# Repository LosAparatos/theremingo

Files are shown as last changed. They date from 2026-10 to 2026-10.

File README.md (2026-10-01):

# Theremingo
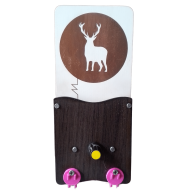
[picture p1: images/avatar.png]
Theremingo


A handmade analog electromagnetic theremin, designed and built by [Los Aparatos](https://losaparatos.com.ar) in Tucumán, Argentina.

## What is it?

Theremingo is an analog theremin — a touchless electronic instrument played by moving your hands near its antennas, which affect pitch and volume through electromagnetic field disturbance. No microcontroller, no code: fully analog circuitry.

## Repository contents

- `/schematics` — circuit design files, created in **EagleCAD (v9.0)**. You'll need Eagle (or a compatible tool like KiCad with an Eagle import plugin) to open the native files.
- `/images` — photos of the finished instrument, including its final enclosure — a deer-shaped antenna cut as an SVG, not included among the schematic files.

## About Los Aparatos

Los Aparatos is an electronic design studio building experimental musical instruments — synthesizers, sound toys and DIY kits — handmade in Tucumán, Argentina, since 2007.

Other instruments: [Auduina](https://gitlab.com/los-aparatos/auduina) (granular synth), Drawdio (a sound pencil that turns drawing into sound), CoyuyoC (a drone synth).

## Where to buy

[losaparatos.com.ar](https://losaparatos.com.ar) · [Tindie](https://www.tindie.com/stores/mateoaparato/) · [Etsy](https://losaparatos.etsy.com) · [Reverb](https://reverb.com/shop/los-aparatos)

## License

[CC BY-NC-SA 4.0](https://creativecommons.org/licenses/by-nc-sa/4.0/)

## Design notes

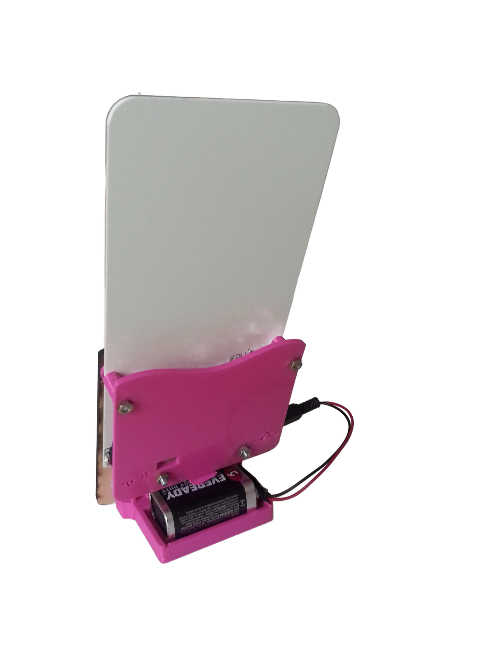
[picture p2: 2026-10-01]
images/2024-01-17T23_02_19.963Z-3806eb7695ffbf5aecbad718a80b5527.png

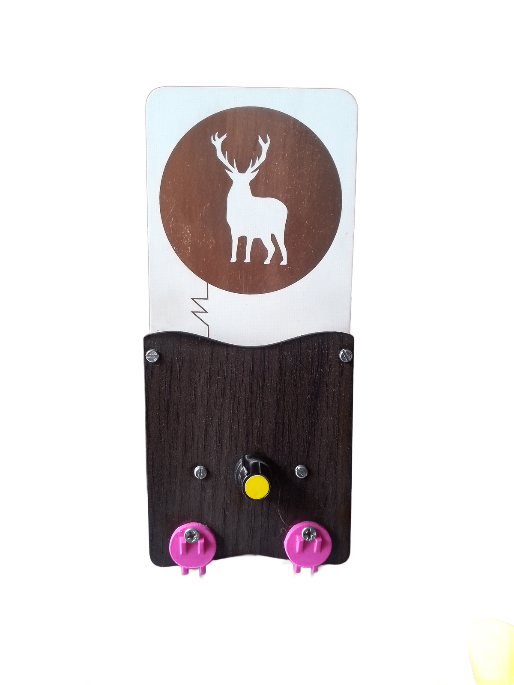
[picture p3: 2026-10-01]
images/2024-01-17T23_02_19.963Z-660f86e07b97e593479c22d0fbce8938.png

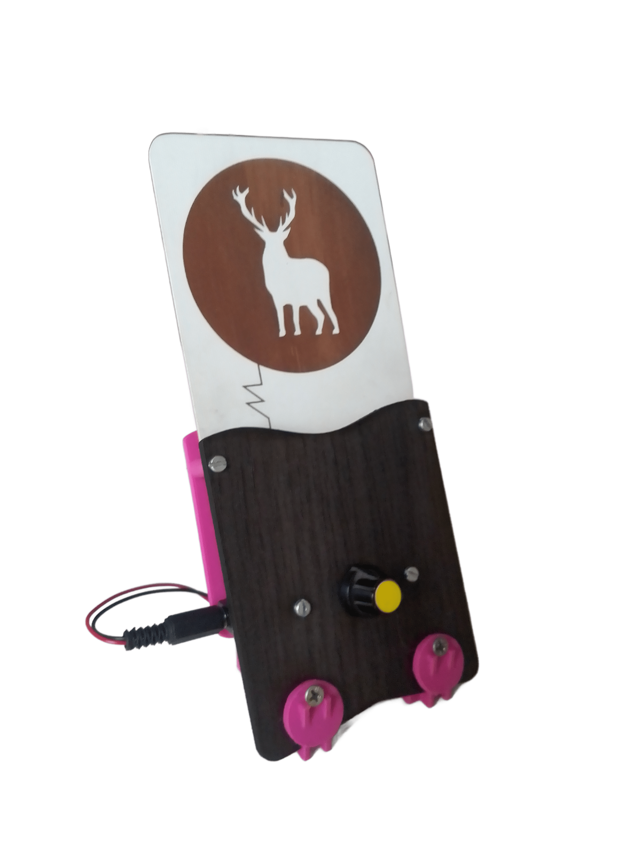
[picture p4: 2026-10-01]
images/2024-01-17T23_02_19.963Z-f0b44ce99c8f05dc5610db6ddd29624c.png

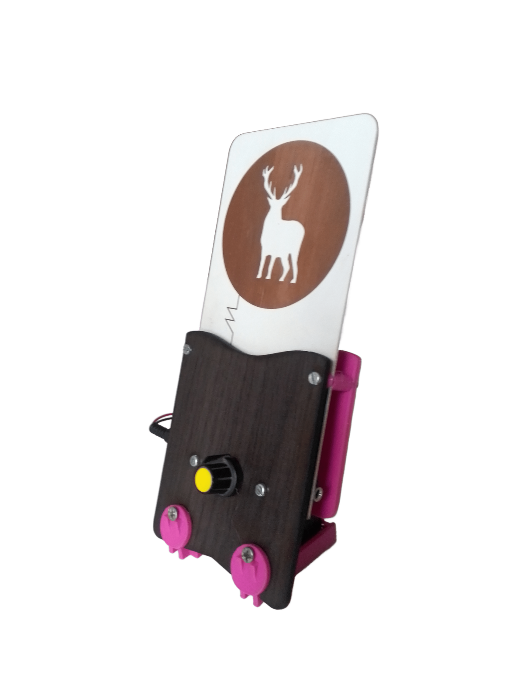
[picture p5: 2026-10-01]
images/2024-01-17T23_02_19.963Z-f9a67fa7e960c82a1b9b4270812b1f55.png

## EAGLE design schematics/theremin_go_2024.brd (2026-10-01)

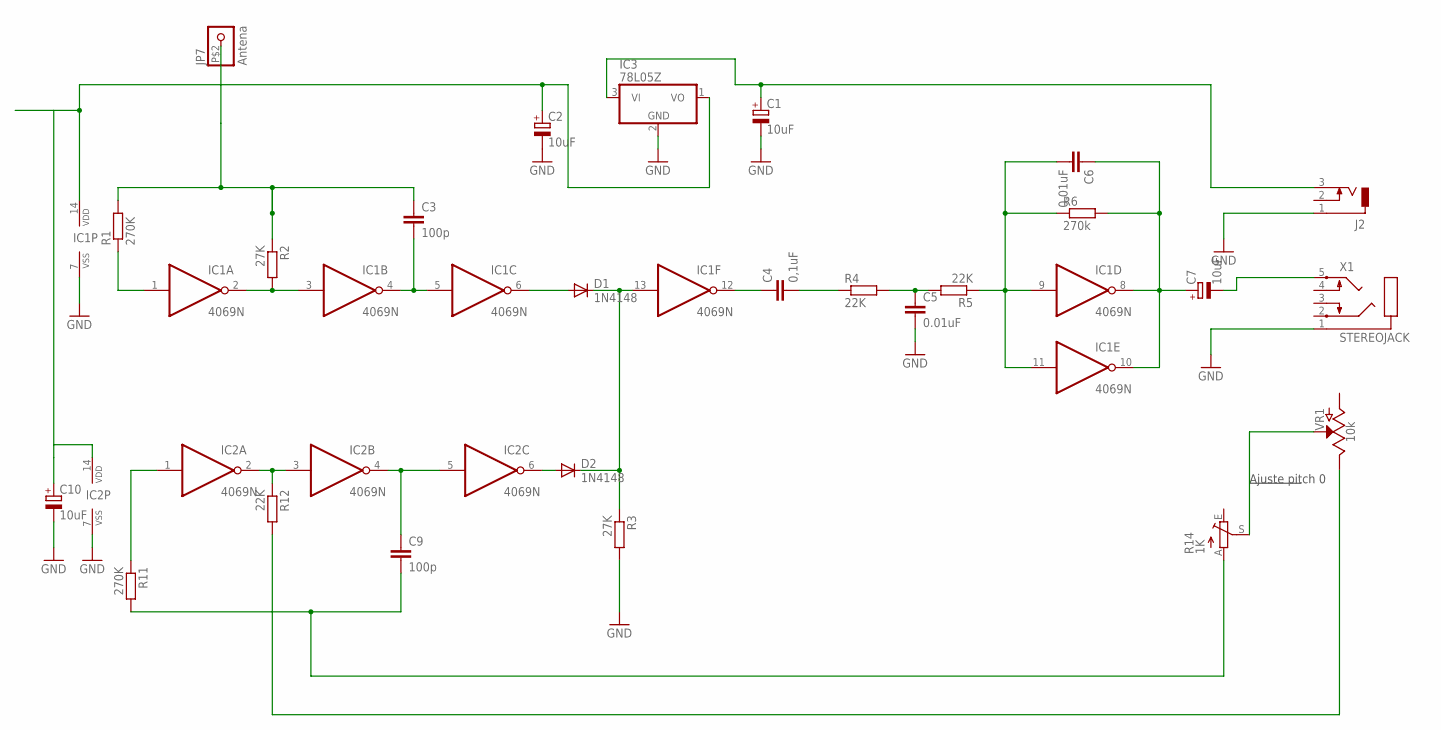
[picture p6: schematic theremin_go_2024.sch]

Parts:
C1, C2, C7, C10: 10uF; E2,5-6E
C3, C9: 100p; C050-030X075
C4: 0,1uF; C050-030X075
C5, C6: 0.01uF; C050-030X075
D1, D2: 1N4148; DO35-7
IC1, IC2: 4069N; DIL14
IC3: 78L05Z; TO92
J2: DCJ0303
JP7: Antena; 1X01
R1, R11: 270K; 0309/10
R2, R3: 27K; 0309/10
R4, R5, R12: 22K; 0309/10
R6: 270k; 0309/10
R14: 1K; S64W
VR1: 10k; POT-PTH-ALPS
X1: STEREOJACK; STX3100

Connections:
GND: C1.-, C2.-, C5.2, C10.-, IC1.7 (VSS), IC2.7 (VSS), IC3.2 (GND), J2.1, R3.2, X1.1
unnamed: C2.+, C10.+, IC1.14 (VDD), IC2.14 (VDD), IC3.1 (VO)
unnamed: C1.+, IC3.3 (VI), J2.3
unnamed: IC1.1 (I), R1.1
unnamed: C3.1, JP7.P$2, R1.2, R2.1
unnamed: IC1.2 (O), IC1.3 (I), R2.2
unnamed: C3.2, IC1.4 (O), IC1.5 (I)
unnamed: D1.A, IC1.6 (O)
unnamed: D1.C, D2.C, IC1.13 (I), R3.1
unnamed: C4.1, IC1.12 (O)
unnamed: C4.2, R4.1
unnamed: C9.2, R11.2, R14.A
unnamed: R14.S, VR1.P$2 (S)
unnamed: C6.2, IC1.9 (I), IC1.11 (I), R5.1, R6.1
unnamed: IC2.1 (I), R11.1
unnamed: C9.1, IC2.4 (O), IC2.5 (I)
unnamed: D2.A, IC2.6 (O)
unnamed: IC2.2 (O), IC2.3 (I), R12.1
unnamed: C6.1, C7.+, IC1.8 (O), IC1.10 (O), R6.2
unnamed: C7.-, X1.5
unnamed: R12.2, VR1.P$1 (E)
unnamed: C5.1, R4.2, R5.2

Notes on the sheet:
Ajuste pitch 0

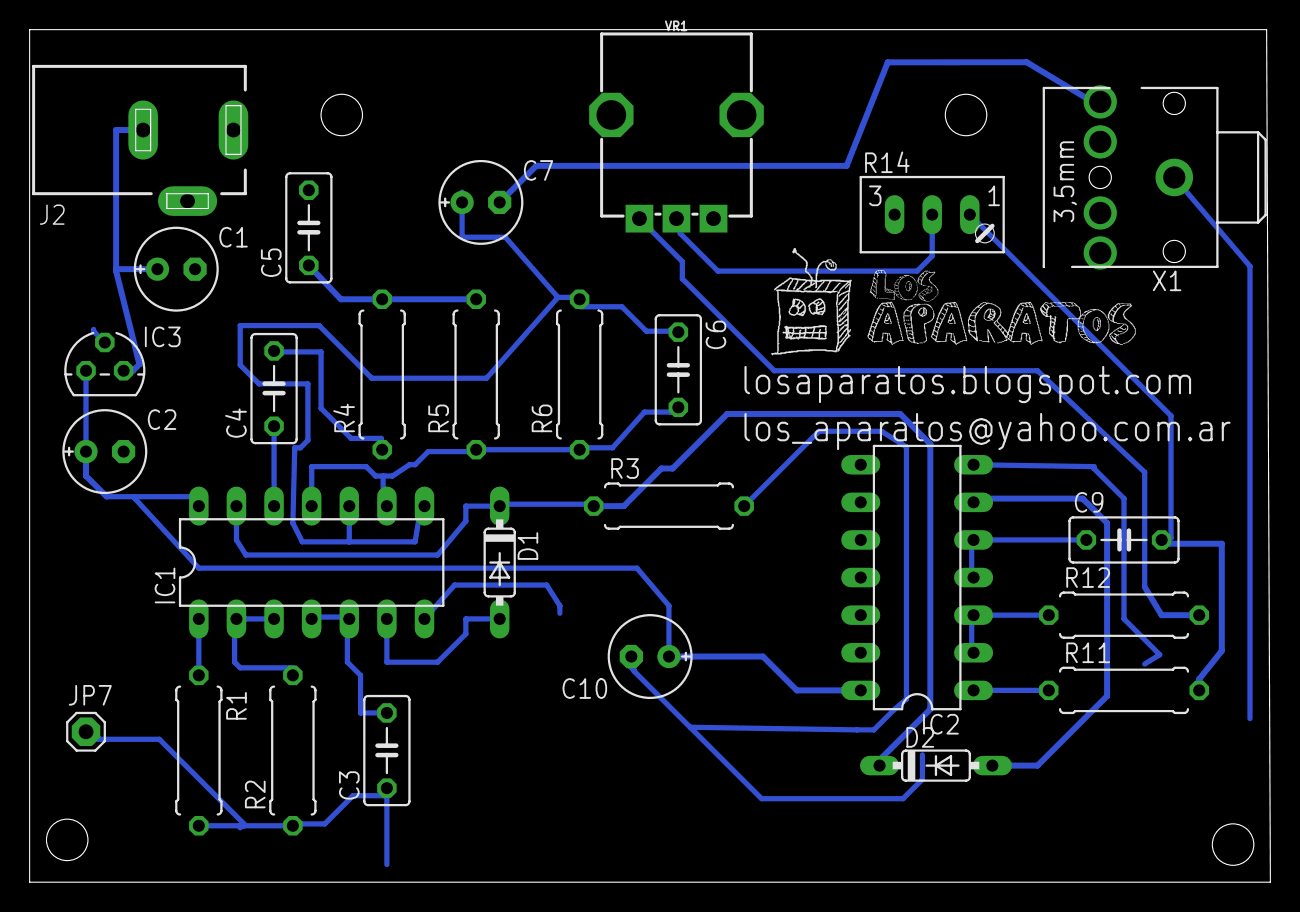
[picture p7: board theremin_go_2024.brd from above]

Board: 2 copper layers, 83.8 x 57.6 mm, 27 parts (0 on the bottom side), 22 nets.

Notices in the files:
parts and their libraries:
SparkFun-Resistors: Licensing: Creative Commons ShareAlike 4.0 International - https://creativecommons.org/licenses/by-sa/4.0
